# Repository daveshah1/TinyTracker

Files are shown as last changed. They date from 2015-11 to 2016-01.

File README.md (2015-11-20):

# TinyTracker
The plan is to create a tiny (<5g) tracker for low-cost, lightweight balloon experiments.

Currently no electronics have been built, but an initial design has been made using KiCad. This is untested and likely has some mistakes. It features:

 * M10748 GPS
 * SX1276 based LoRa radio with TCXO (for ultimate performace with very low data rates)
 * STM32F048 MCU
 * MS5637 temperature/pressure sensor
 * CAT24M01 EEPROM for logging
 
It is designed to run off a small lithium polymer battery such as [PRT-00731](https://www.sparkfun.com/products/731) which, depending on logging and transmission interval, should give a battery life of over 10 hours.

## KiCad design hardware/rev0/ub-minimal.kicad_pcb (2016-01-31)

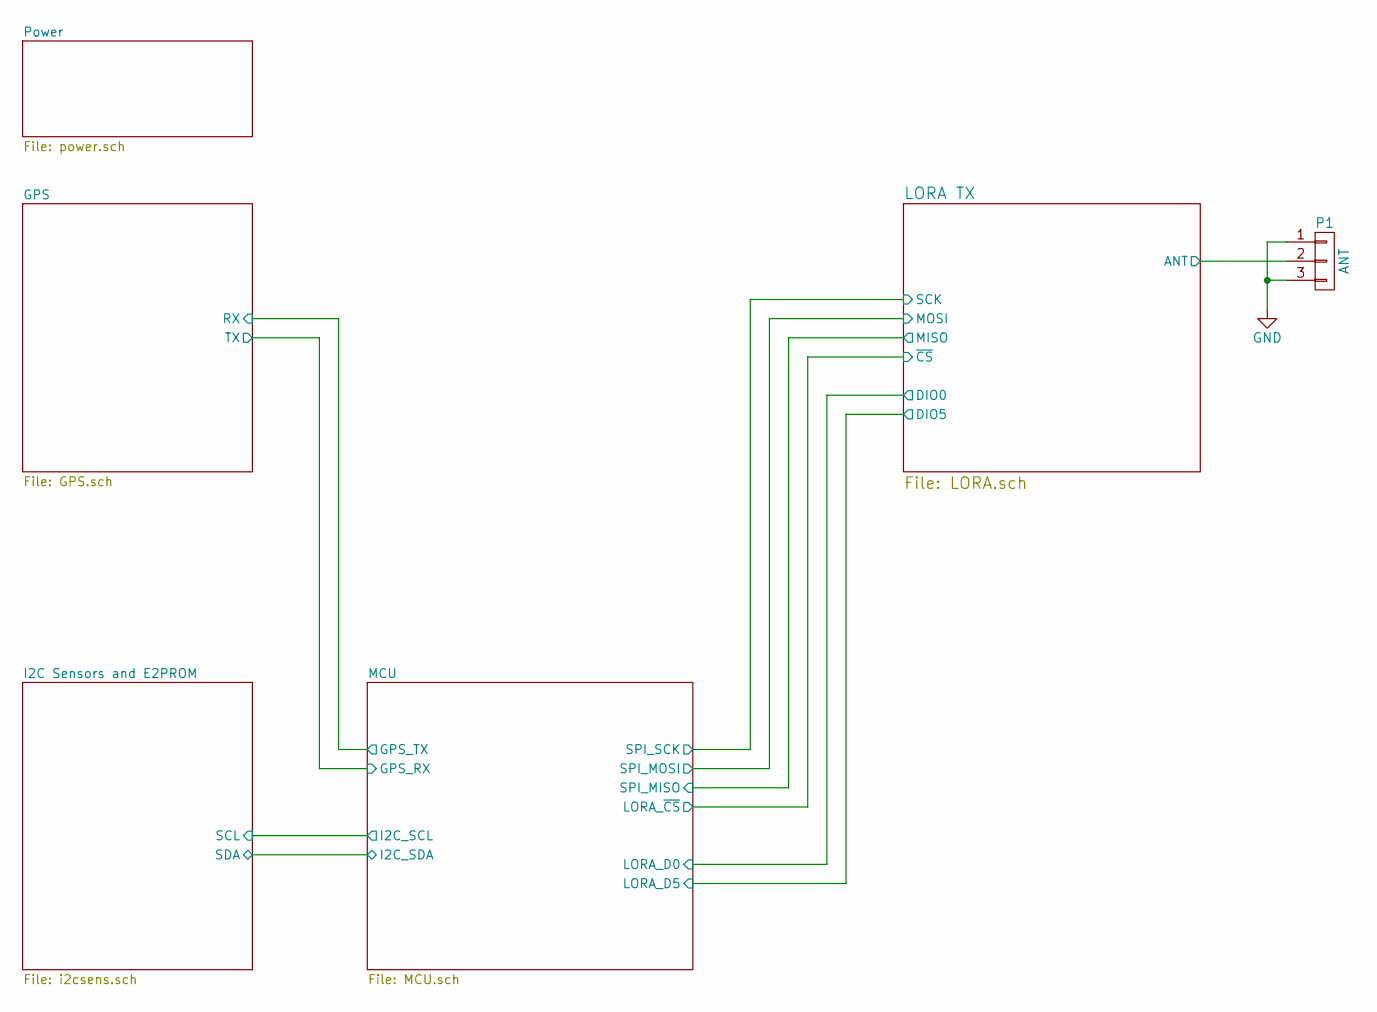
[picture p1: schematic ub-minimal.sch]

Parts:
P1: ANT; ANT_50ohm

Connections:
/LORA TX/ANT: P1.2; also elsewhere on the board
GND: P1.1, P1.3; also elsewhere on the board

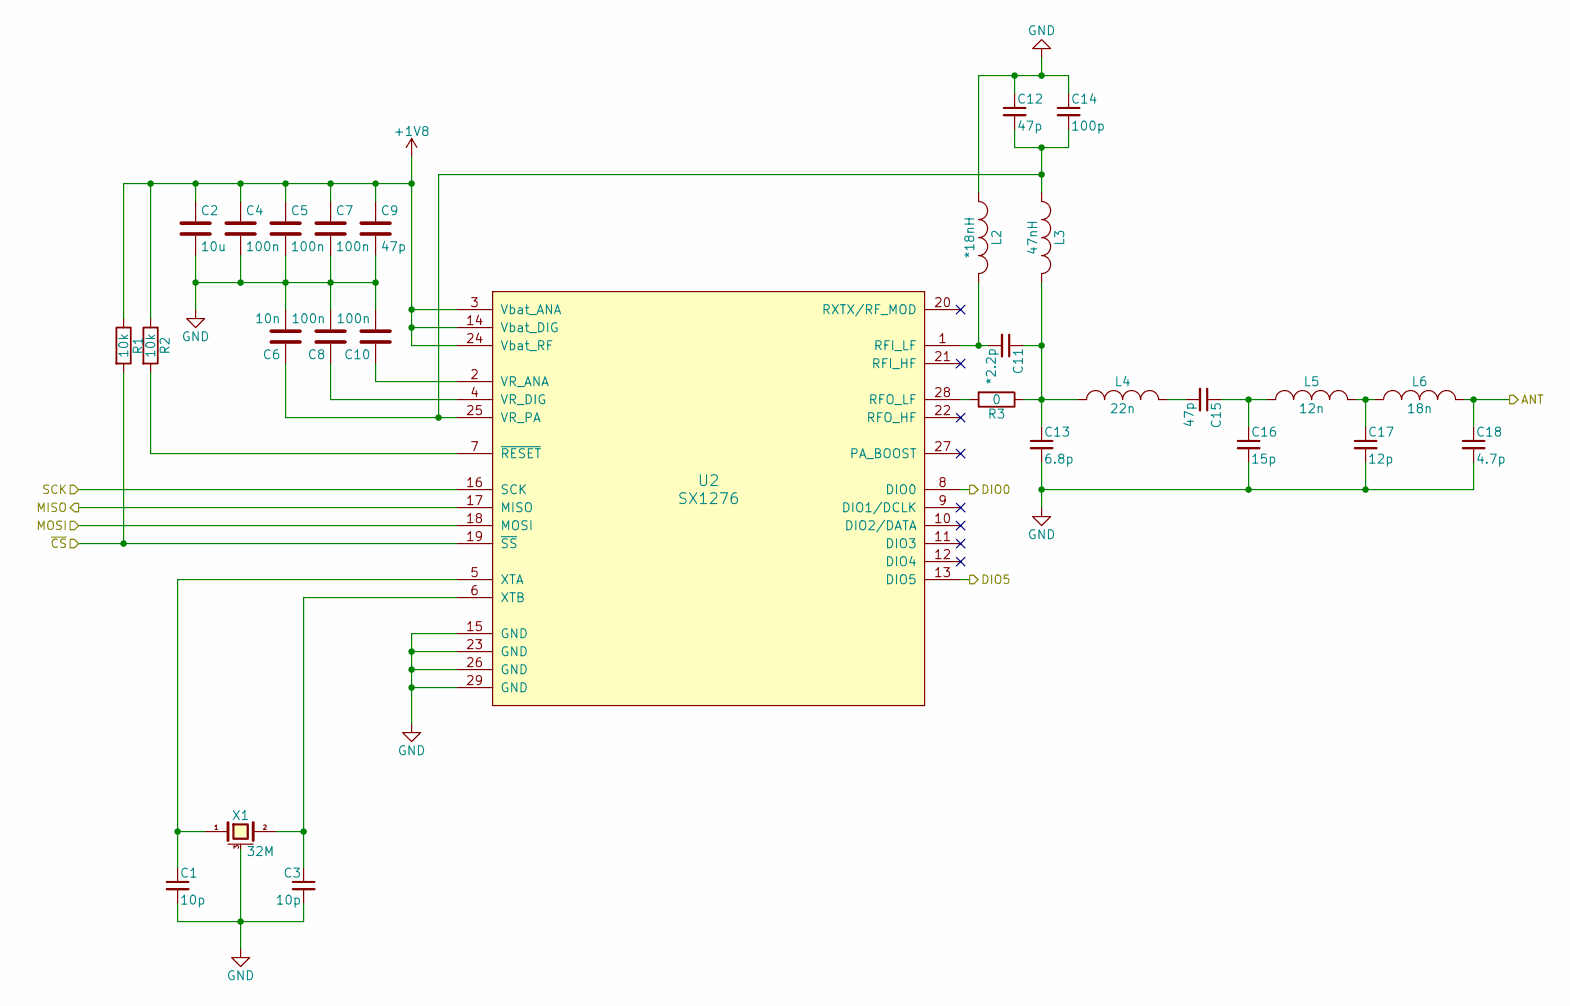
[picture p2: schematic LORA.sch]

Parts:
C1, C3: 10p; C_0402
C2: 10u; C_0805
C4, C5, C7, C8, C10: 100n; C_0402
C6: 10n; C_0402
C9, C12, C15: 47p; C_0402
C11: *2.2p; C_0402
C13: 6.8p; C_0402
C14: 100p; C_0402
C16: 15p; C_0402
C17: 12p; C_0402
C18: 4.7p; C_0402
L2: *18nH; R_0402
L3: 47nH; R_0402
L4: 22n; R_0402
L5: 12n; R_0402
L6: 18n; R_0402
R1, R2: 10k; R_0402
R3: 0; R_0402
U2: SX1276; QFP_28_0.65
X1: 32M; XTAL-2x2.5

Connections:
+1V8: C2.1, C4.1, C5.1, C7.1, C9.1, R1.1, R2.1, U2.3 (Vbat_ANA), U2.14 (Vbat_DIG), U2.24 (Vbat_RF); also elsewhere on the board
/LORA TX/ANT: C18.1, L6.2; also elsewhere on the board
/LORA TX/DIO0: U2.8 (DIO0); also elsewhere on the board
/LORA TX/DIO5: U2.13 (DIO5); also elsewhere on the board
/LORA TX/MISO: U2.17 (MISO); also elsewhere on the board
/LORA TX/MOSI: U2.18 (MOSI); also elsewhere on the board
/LORA TX/SCK: U2.16 (SCK); also elsewhere on the board
/MCU/LORA_~CS: R1.2, U2.19 (~SS); also elsewhere on the board
GND: C1.2, C2.2, C3.2, C4.2, C5.2, C6.2, C7.2, C8.2, C9.2, C10.2, C12.1, C13.2, C14.1, C16.2, C17.2, C18.2, L2.1, U2.15 (GND), U2.23 (GND), U2.26 (GND), U2.29 (GND), X1.3 (case); also elsewhere on the board
unnamed: C1.1, U2.5 (XTA), X1.1
unnamed: C3.1, U2.6 (XTB), X1.2
unnamed: C8.1, U2.4 (VR_DIG)
unnamed: C10.1, U2.2 (VR_ANA)
unnamed: C11.1, C13.1, L3.2, L4.1, R3.1
unnamed: C11.2, L2.2, U2.1 (RFI_LF)
unnamed: C6.1, C12.2, C14.2, L3.1, U2.25 (VR_PA)
unnamed: C15.1, C16.1, L5.1
unnamed: C15.2, L4.2
unnamed: C17.1, L5.2, L6.1
unnamed: R2.2, U2.7 (~RESET)
unnamed: R3.2, U2.28 (RFO_LF)

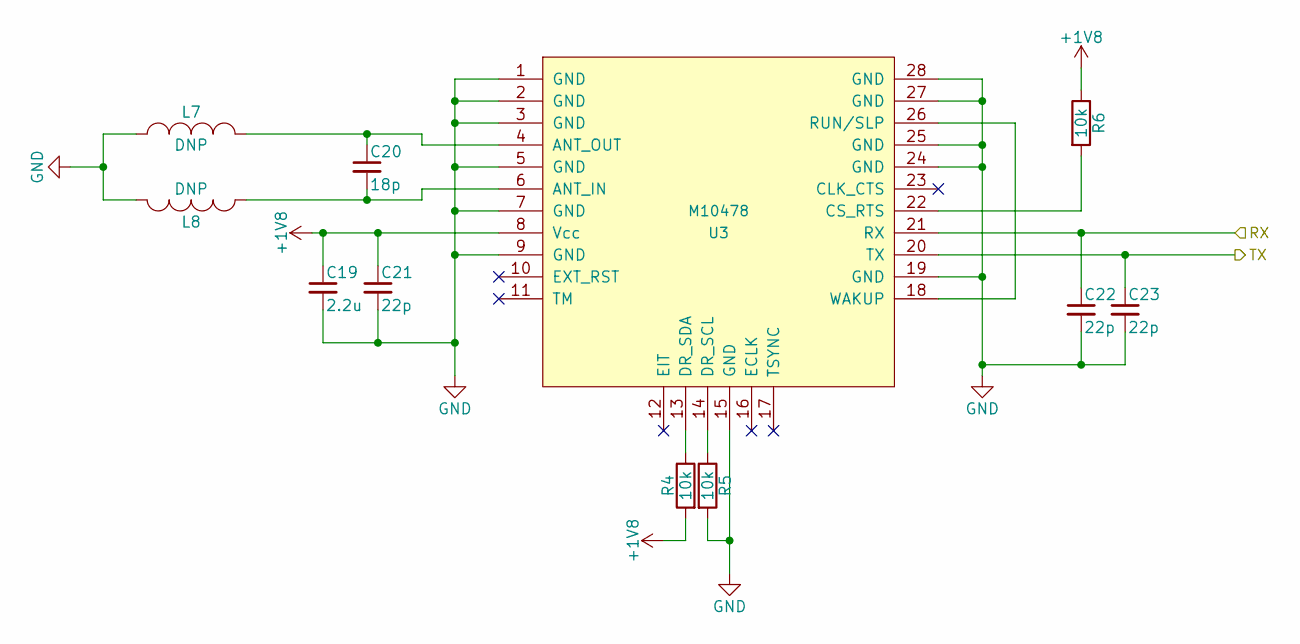
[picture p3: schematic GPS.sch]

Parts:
C19: 2.2u; C_0603
C20: 18p; C_0402
C21, C22, C23: 22p; C_0402
L7, L8: DNP; R_0402
R4, R5, R6: 10k; R_0402
U3: M10478; M10748

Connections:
+1V8: C19.1, C21.1, R4.2, R6.1, U3.8 (Vcc); also elsewhere on the board
/MCU/GPS_RX: C23.1, U3.20 (TX); also elsewhere on the board
/MCU/GPS_TX: C22.1, U3.21 (RX); also elsewhere on the board
GND: C19.2, C21.2, C22.2, C23.2, L7.1, L8.1, R5.2, U3.1 (GND), U3.2 (GND), U3.3 (GND), U3.5 (GND), U3.7 (GND), U3.9 (GND), U3.15 (GND), U3.19 (GND), U3.24 (GND), U3.25 (GND), U3.27 (GND), U3.28 (GND); also elsewhere on the board
unnamed: C20.1, L7.2, U3.4 (ANT_OUT)
unnamed: C20.2, L8.2, U3.6 (ANT_IN)
unnamed: R4.1, U3.13 (DR_SDA)
unnamed: R5.1, U3.14 (DR_SCL)
unnamed: R6.2, U3.22 (CS_RTS)
unnamed: U3.18 (WAKUP), U3.26 (RUN/SLP)

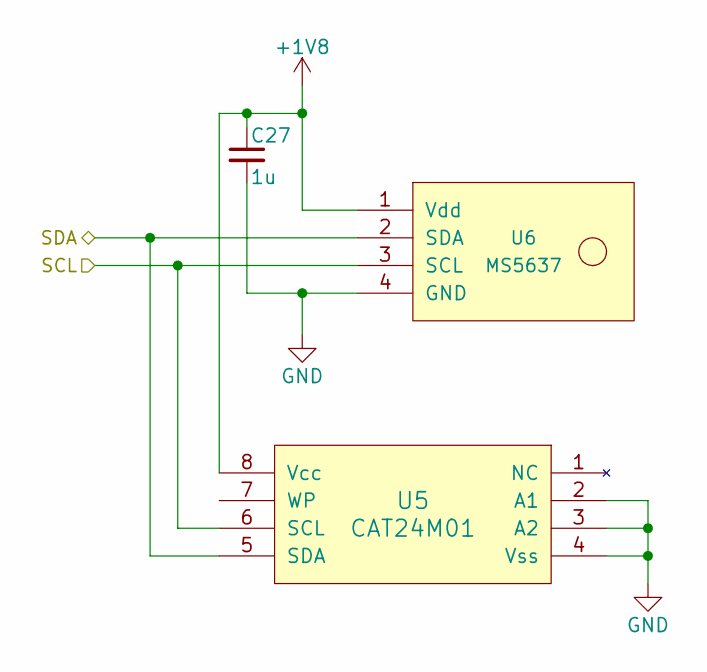
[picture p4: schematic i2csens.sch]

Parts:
C27: 1u; C_0603
U5: CAT24M01; UDFN8
U6: MS5637

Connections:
+1V8: C27.1, U5.8 (Vcc), U6.1 (Vdd); also elsewhere on the board
/MCU/I2C_SCL: U5.6 (SCL), U6.3 (SCL); also elsewhere on the board
/MCU/I2C_SDA: U5.5 (SDA), U6.2 (SDA); also elsewhere on the board
GND: C27.2, U5.2 (A1), U5.3 (A2), U5.4 (Vss), U6.4 (GND); also elsewhere on the board

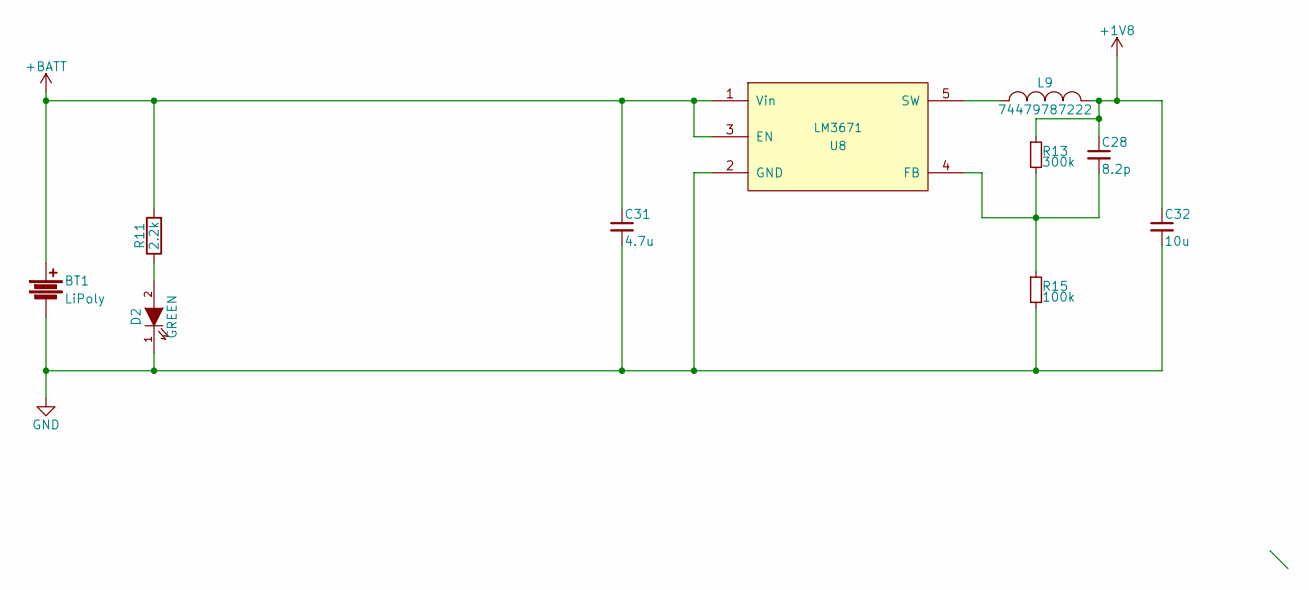
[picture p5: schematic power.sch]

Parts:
BT1: LiPoly; S2B-PH-SM4-TB
C28: 8.2p; C_0402
C31: 4.7u; C_0805
C32: 10u; C_0805
D2: GREEN; LED-0603
L9: 74479787222; Neosid_Inductor_SM-NE29_SMD1008
R11: 2.2k; R_0402
R13: 300k; R_0402
R15: 100k; R_0402
U8: LM3671; SOT-23-5

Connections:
+1V8: C28.1, C32.1, L9.2, R13.1; also elsewhere on the board
+BATT: BT1.1, C31.1, R11.2, U8.1 (Vin), U8.3 (EN)
GND: BT1.2, C31.2, C32.2, D2.1 (K), R15.2, U8.2 (GND); also elsewhere on the board
unnamed: C28.2, R13.2, R15.1, U8.4 (FB)
unnamed: D2.2 (A), R11.1
unnamed: L9.1, U8.5 (SW)

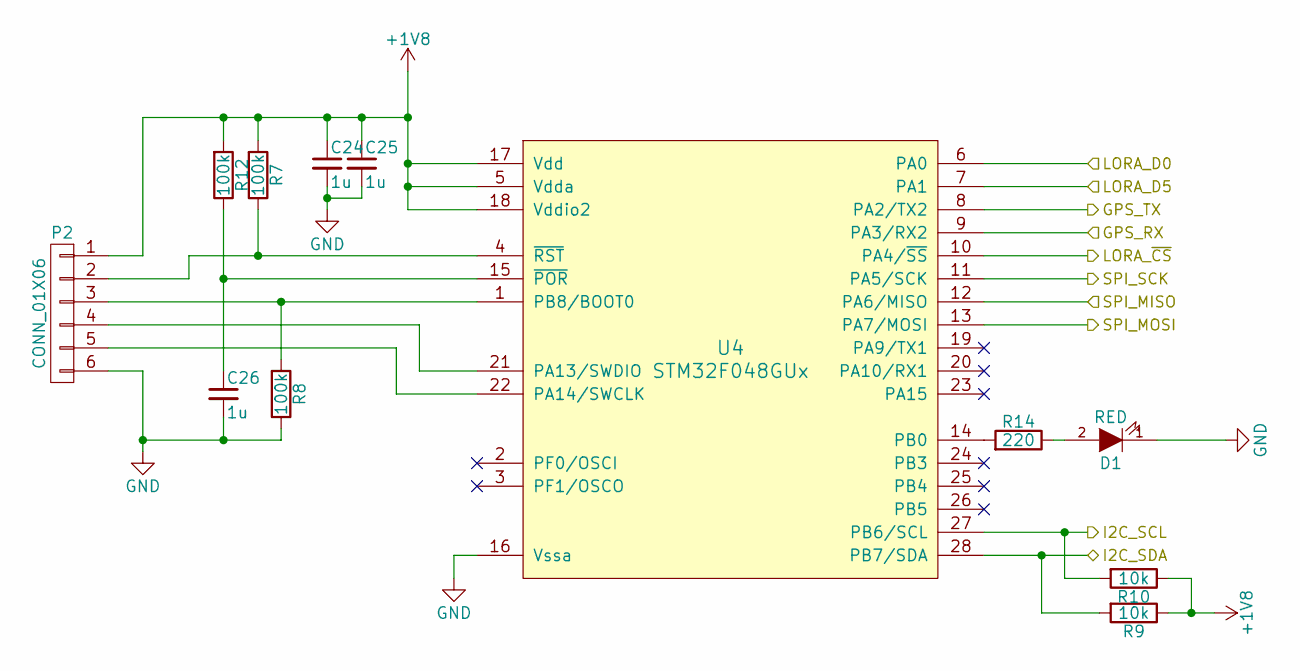
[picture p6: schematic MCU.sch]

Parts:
C24, C25, C26: 1u; C_0603
D1: RED; LED-0603
P2: CONN_01X06; 6-1.27mm
R7, R8, R12: 100k; R_0402
R9, R10: 10k; R_0402
R14: 220; R_0402
U4: STM32F048GUx; UFQFPN28

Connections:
+1V8: C24.1, C25.1, P2.1, R7.2, R9.1, R10.1, R12.2, U4.5 (Vdda), U4.17 (Vdd), U4.18 (Vddio2); also elsewhere on the board
/LORA TX/DIO0: U4.6 (PA0); also elsewhere on the board
/LORA TX/DIO5: U4.7 (PA1); also elsewhere on the board
/LORA TX/MISO: U4.12 (PA6/MISO); also elsewhere on the board
/LORA TX/MOSI: U4.13 (PA7/MOSI); also elsewhere on the board
/LORA TX/SCK: U4.11 (PA5/SCK); also elsewhere on the board
/MCU/GPS_RX: U4.9 (PA3/RX2); also elsewhere on the board
/MCU/GPS_TX: U4.8 (PA2/TX2); also elsewhere on the board
/MCU/I2C_SCL: R10.2, U4.27 (PB6/SCL); also elsewhere on the board
/MCU/I2C_SDA: R9.2, U4.28 (PB7/SDA); also elsewhere on the board
/MCU/LORA_~CS: U4.10 (PA4/~SS); also elsewhere on the board
GND: C24.2, C25.2, C26.2, D1.1 (K), P2.6, R8.1, U4.16 (Vssa); also elsewhere on the board
unnamed: C26.1, R12.1, U4.15 (~POR)
unnamed: D1.2 (A), R14.1
unnamed: P2.2, R7.1, U4.4 (~RST)
unnamed: P2.3, R8.2, U4.1 (PB8/BOOT0)
unnamed: P2.4, U4.21 (PA13/SWDIO)
unnamed: P2.5, U4.22 (PA14/SWCLK)
unnamed: R14.2, U4.14 (PB0)

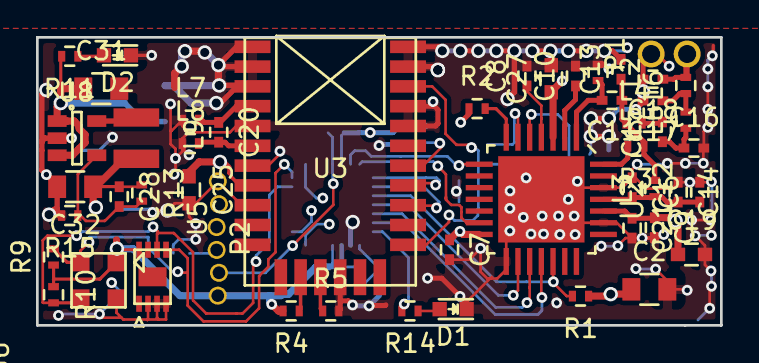
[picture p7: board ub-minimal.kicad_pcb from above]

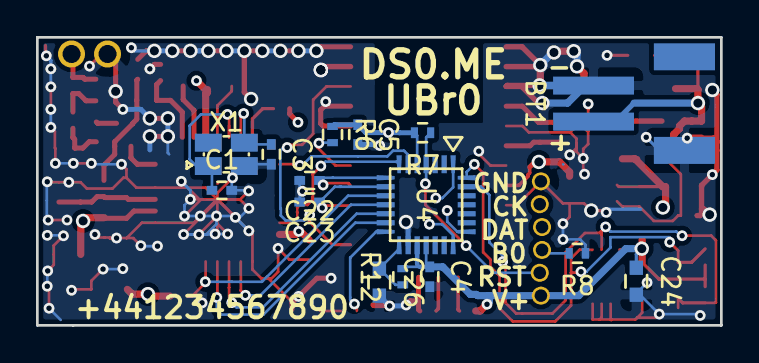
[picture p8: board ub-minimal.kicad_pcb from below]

Board: 4 copper layers, 38.0 x 16.0 mm, 65 parts (15 on the bottom side), 42 nets.

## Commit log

2015-11-20 Add hardware revision 0
    Currently unchecked & untested
    [GPS.sch, LORA.sch, MCU.sch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]
2016-01-26 Replace TCXO with XTAL
    Planned TCXO became obsolete and hard to source, high quality XTAL
    should be good enough with possible temperature compensation in
    software.
    [LORA.sch, MCU.sch, power.sch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]
2016-01-27 DRC alterations, generate gerbers
    [MCU.sch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]
2016-01-28 Various fixes and tweaks
    [ub-minimal.kicad_pcb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]
2016-01-31 Add FB network
    Allow system to run off 2V if needed
    [power.sch, ub-minimal.kicad_pcb]
